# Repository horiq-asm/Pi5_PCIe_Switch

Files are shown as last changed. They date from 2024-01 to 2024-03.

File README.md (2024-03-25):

Pi5のPCIeコネクタ情報が公開されたのでASM1184eをつないでPCIe　M.2コネクタ4portの動作検証しました。<br>
結論としては4ポート認識とA-keyの2.5GbpsLAN基板,M-keyの各種USB3基板が動作しました。<br>
ただし、M.2SSDがまだ現状認識できていません。　　＜＜対策済　<br>
pcie信号間クロストーク対策と、電源強化を行ってM.2SSDは正常に認識されました。<br>
回路図はまだ公開しませんが実験基板のpcdデータをKicadで公開します。<br>
<br>
youtubeに動作画面を載せています。<br>
https://youtu.be/G8ONZqBu1oo

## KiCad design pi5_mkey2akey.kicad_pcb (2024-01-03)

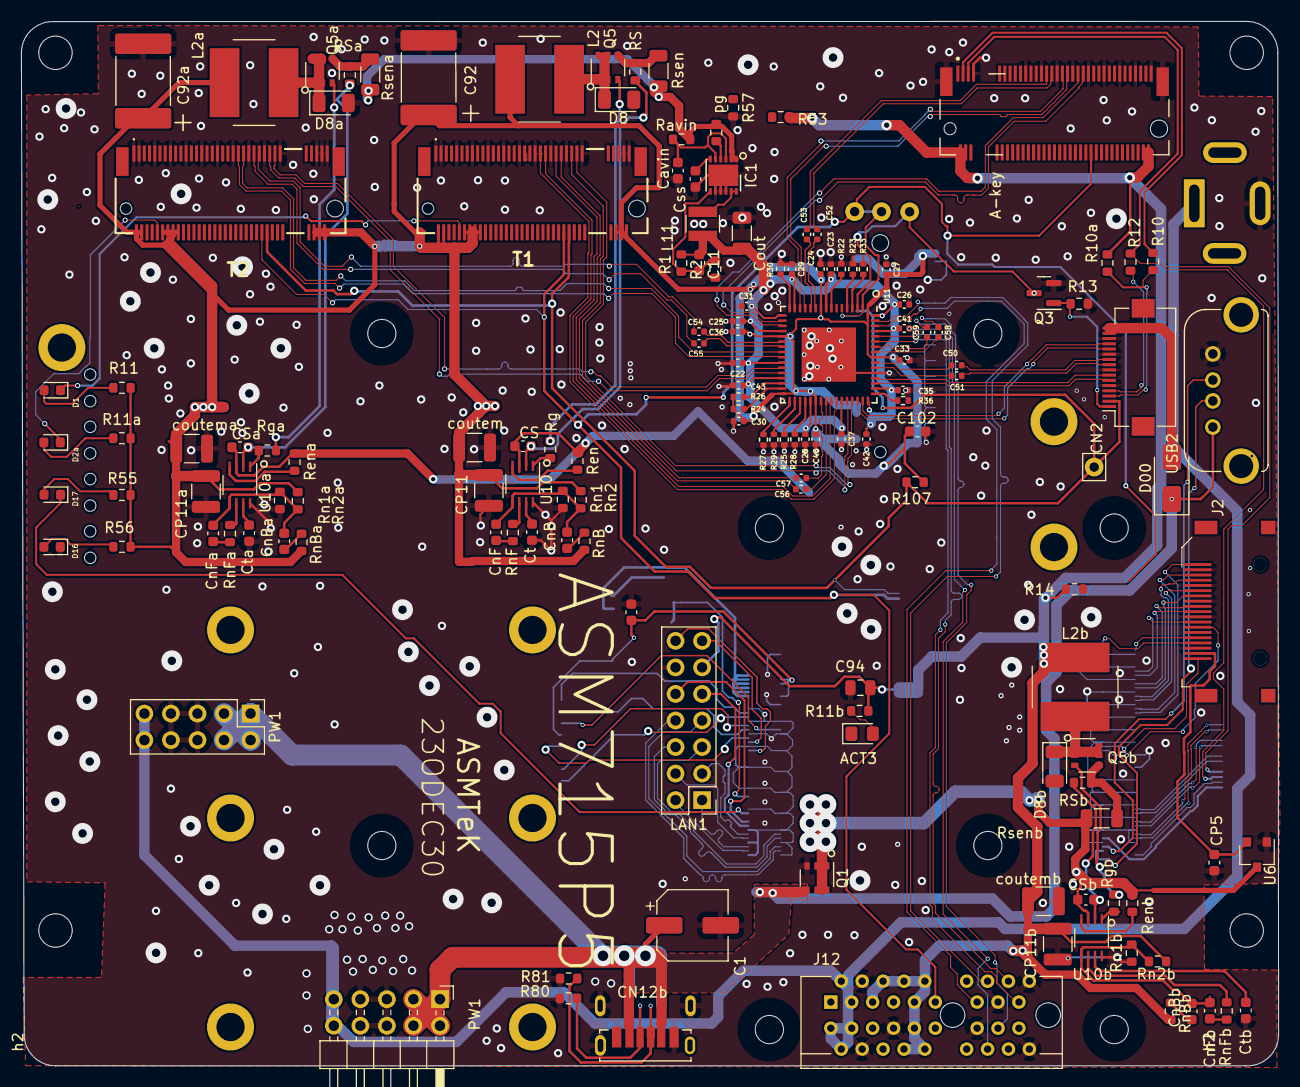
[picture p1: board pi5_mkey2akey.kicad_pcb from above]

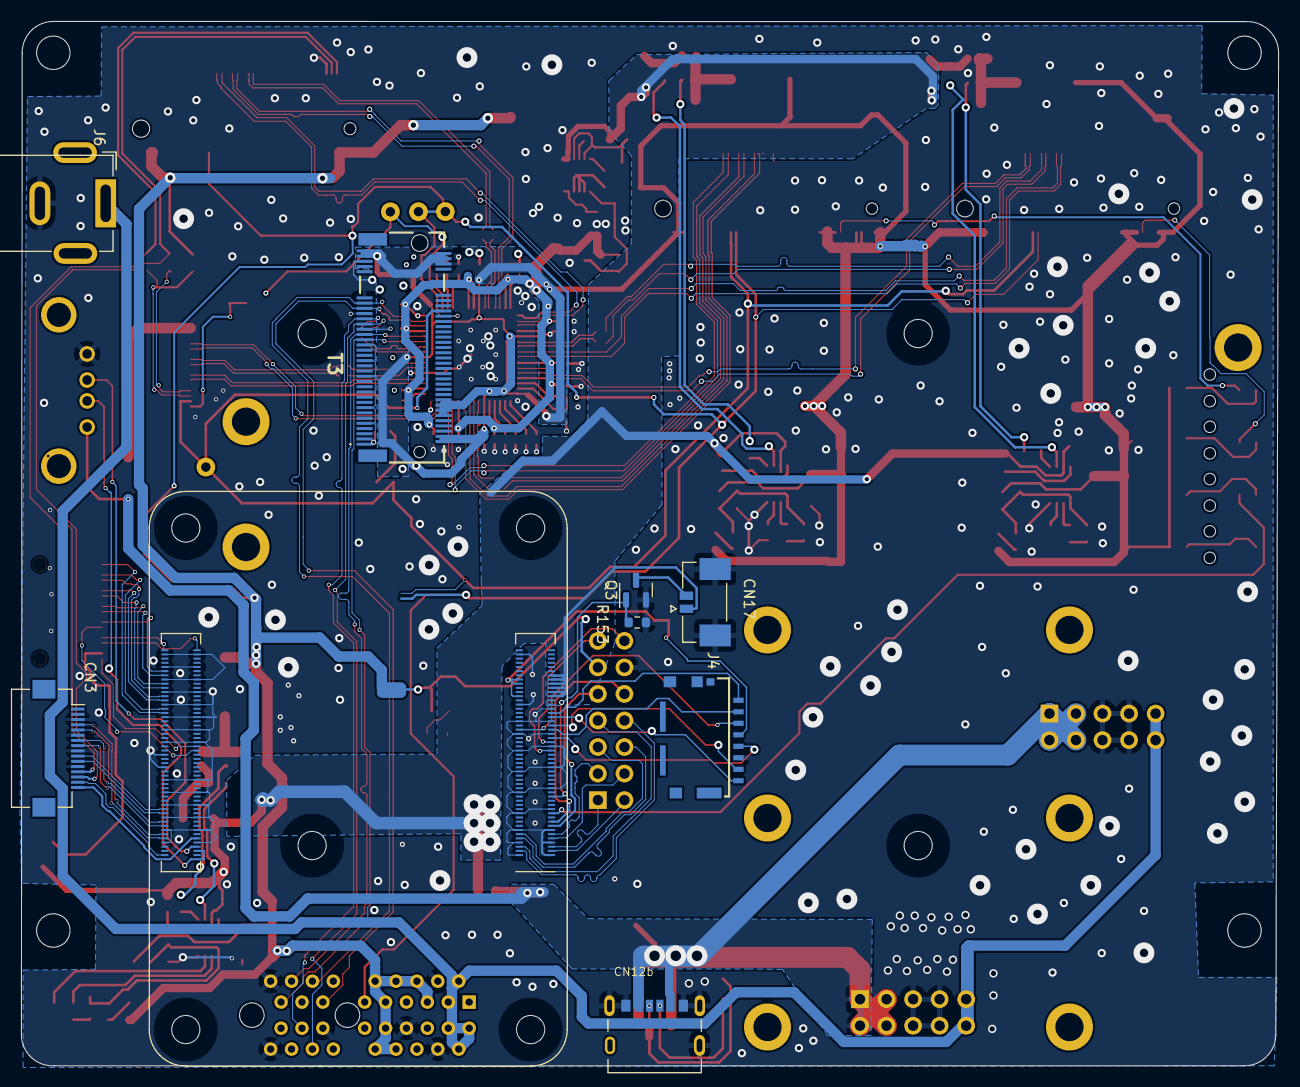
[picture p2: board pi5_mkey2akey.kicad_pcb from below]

Board: 2 copper layers, 120.3 x 100.0 mm, 167 parts (9 on the bottom side), 156 nets.

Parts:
C1: RSA0J331MCN1GS; CP_Elec_6.3x5.8
C11: 25p; C_0603_1608Metric
C22, C23, C24, C25, C26, C27, C28, C29, C30, C31, C33, C35, C36, C37, C41, C42, C43, C46, C50, C51, C52, C53, C54, C55, C56, C57, C58, C59: 100nF; C_0402_1005Metric
C92, C92a: ECASD40J476M025K00; C_2220_5650Metric_Pad1.97x5.40mm_HandSolder
C94: GRM188R61C106MAALD; C_0805_2012Metric
C102: 104; C_0603_1608Metric
CN2, CN3: Hirose_FH12-16S-0.5SH_1x16-1MP_P0.50mm_Horizontal
CN12b: CUI_UJC-VP-3-SMT-TR
CN12b#2: CUI_UJC-HP-3-SMT-TR
CN17: MOLEX_533980271
CP4: 100n; C_0603_1608Metric
CP5: 104; C_0603_1608Metric
CP11, CP11a, CP11b: C_1210_3225Metric
CS: 22n; C_0603_1608Metric
CSa: 22n; C_0603_1608Metric
CSb: 22n; C_0603_1608Metric
Cavin: 10n; C_0603_1608Metric
CnB: 220p; C_0603_1608Metric
CnBa: 220p; C_0603_1608Metric
CnBb: 220p; C_0603_1608Metric
CnF: 2.2n; C_0603_1608Metric
CnFa: 2.2n; C_0603_1608Metric
CnFb: 2.2n; C_0603_1608Metric
Cout: 22u; C_1206_3216Metric
Css: 470p; C_0603_1608Metric
Ct: 1n; C_0603_1608Metric
Cta: 1n; C_0603_1608Metric
Ctb: 1n; C_0603_1608Metric
D00: SR54F; D_SMA
D1, D2a: yellow; LED_0603_1608Metric
D1b: ACT3; LED_0805_2012Metric_Pad1.15x1.40mm_HandSolder
D8, D8a, D8b: SS2040FL; D_1206_3216Metric
D16: green; LED_0603_1608Metric
D17: red; LED_0603_1608Metric
IC1: RP510L00; DFN-12-1EP_3x3mm_P0.5mm_EP2.05x2.86mm
J2: HDMI_A_Female_2000-1-2-41-00-BK; HDMI
J4: 105162-0001
J6: BarrelJack_GCT_DCJ200-10-A_Horizontal
J12: 10018783-11200TLF; PCIex1-36
L2, L2a, L2b: SRN6045TA-4R7M; L_Bourns_SRN8040TA
L11: 1u; L_Abracon_ASPI-3012S
LAN1: PinHeader_2x07_P2.54mm_Vertical
Module1: ComputeModule4; Raspberry-Pi-4-Compute-Module
PW1: PinHeader_2x05_P2.54mm_Vertical
PW1#2: PinHeader_2x05_P2.54mm_Horizontal
Q1, Q5, Q5a, Q5b: SSM6J808R; TSOP-6_1.65x3.05mm_P0.95mm
Q3, Q3#2: BSS138-TP; SOT-23
R1, R2: 20k; R_0603_1608Metric
R10, R12: 0; R_0603_1608Metric
R10a: 2.2k; R_0603_1608Metric
R11, R11a, R11b, R55, R56, R153: 1k; R_0603_1608Metric
R13: 10k; R_0603_1608Metric
R14, R80, R81: 5.1k; R_0603_1608Metric
R22, R23, R25, R27: 1K; R_0402_1005Metric
R24, R26, R28, R29, R33: 10K; R_0402_1005Metric
R30, R36: 12.1K; R_0402_1005Metric
R53, R57: 51k; R_0603_1608Metric
R107: 100k; R_0603_1608Metric
RS: 20; R_0603_1608Metric
RSa: 20; R_0603_1608Metric
RSb: 20; R_0603_1608Metric
Ravin: 1; R_0603_1608Metric
Ren: 10k; R_0603_1608Metric
Rena: 10k; R_0603_1608Metric
Renb: 10k; R_0603_1608Metric
Rg: 20; R_0603_1608Metric
Rga: 20; R_0603_1608Metric
Rgb: 20; R_0603_1608Metric
Rn1, Rn1a, Rn1b: 10k; R_0603_1608Metric
Rn2, Rn2a, Rn2b: 30.9k; R_0603_1608Metric
RnB: 1k; R_0603_1608Metric
RnBa: 1k; R_0603_1608Metric
RnBb: 1k; R_0603_1608Metric
RnF: 8.2k; R_0603_1608Metric
RnFa: 8.2k; R_0603_1608Metric
RnFb: 8.2k; R_0603_1608Metric
Rsen: 27m; R_1206_3216Metric
Rsena: 27m; R_1206_3216Metric
Rsenb: 27m; R_1206_3216Metric
T1, T2, T3: MDT420M01001
T4: 2199230-8; b9973afb-34f9-4941-8c1f-dffebdb6dde0
U6: AP2331W; SC-59
U10, U10a, U10b: NJW4160R-TE2; SOT-23-8_Handsoldering
U11: ASM1184e; QFN-64-1EP_9x9mm_P0.5mm_EP5.2x5.2mm
USB2: USB-A-S-X-X-VT
coutem: C_1210_3225Metric
coutema: C_1210_3225Metric
coutemb: C_1210_3225Metric
h2, h2#2, h10, h15: MountingHole_3.2mm_M3
h4, h4#2, h6, h7: SLP3-150-100-F; MountingHole_2.1mm
h5, h5#2, h5#3, h5#4: MountingHole_1.1mm; MountingHole_2.1mm
pg: 100k; R_0603_1608Metric

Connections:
1v2: C11.2, C22.1, C23.1, C25.1, C26.1, C28.1, C29.1, C31.1, C35.1, C37.1, C41.1, C42.1, C43.1, Cout.1, L11.2, R1.2, U11.9 (1V2), U11.15 (1V2), U11.17 (1V2), U11.20 (1V2), U11.26 (1V2), U11.29 (1V2), U11.37 (1V2), U11.43 (1V2), U11.48 (1V2), U11.50 (1V2), U11.61 (1V2), U11.64 (1V2)
3.3V: C94.2, CP11b.2, J12.A5 (TCK), J12.A6 (TDI), J12.A8 (TMS), J12.A9 (+3.3V), J12.A10 (+3.3V), J12.B8 (+3.3v), J12.B9 (nTRST), J12.B10 (+3.3vAUX), L2b.2, LAN1.11, R10a.1, R11b.2, R14.1, R53.1, Rn2b.1, RnBb.1, T4.2, T4.4, T4.72, T4.74, coutemb.1
3.3vema: C24.1, C27.1, C30.1, C33.1, C36.1, C46.1, C92.1, C92a.1, C102.1, CP11.2, CP11a.2, L2.2, L2a.2, R11.2, R11a.2, R24.1, R26.1, R55.2, R56.2, R107.2, Rn2.1, Rn2a.1, RnB.1, RnBa.1, T1.2, T1.4, T1.12, T1.14, T1.16, T1.18, T1.70, T1.72, T1.74, T2.2, T2.4, T2.12, T2.14, T2.16, T2.18, T2.70, T2.72, T2.74, T3.2, T3.4, T3.12, T3.14, T3.16, T3.18, T3.70, T3.72, T3.73, T3.74, T3.75, U11.1 (3V_AUX), U11.10 (3V3), U11.21 (3V3), U11.32 (3V3), U11.38 (3V3), U11.56 (3V3), coutem.1, coutema.1
5VIN: C1.1, CN12b.A9, CN12b.B9, CN12b#2.A9, CN12b#2.B9, D00.1, PW1.1, PW1.2, PW1.3, PW1.4, PW1#2.1, PW1#2.2, PW1#2.3, PW1#2.4, Q1.4, USB2.1
12V: J6.1, J12.A2 (+12V), J12.A3 (+12V), J12.B1 (+12v), J12.B2 (+12v), J12.B3 (+12v), PW1.9, PW1.10, PW1#2.9, PW1#2.10
1184e_TX_N: C51.2, U11.54 (TXP_IN)
1184e_TX_P: C50.2, U11.55 (TXN_IN)
A5: CN12b.A5, CN12b#2.B5, R81.1
B5: CN12b.B5, CN12b#2.A5, R80.1
Ethernet_Pair0_N: LAN1.6, Module1.10 (Ethernet_Pair0_N)
Ethernet_Pair0_P: LAN1.5, Module1.12 (Ethernet_Pair0_P)
Ethernet_Pair1_N: LAN1.7, Module1.6 (Ethernet_Pair1_N)
Ethernet_Pair1_P: LAN1.8, Module1.4 (Ethernet_Pair1_P)
Ethernet_Pair2_N: LAN1.4, Module1.9 (Ethernet_Pair2_N)
Ethernet_Pair2_P: LAN1.3, Module1.11 (Ethernet_Pair2_P)
Ethernet_Pair3_N: LAN1.1, Module1.5 (Ethernet_Pair3_N)
Ethernet_Pair3_P: LAN1.2, Module1.3 (Ethernet_Pair3_P)
Ethernet_nLED2: LAN1.10, Module1.17 (Ethernet_nLED2(3.3v))
Ethernet_nLED3: LAN1.9, Module1.15 (Ethernet_nLED3(3.3v))
GND: C1.2, C22.2, C23.2, C24.2, C25.2, C26.2, C27.2, C28.2, C29.2, C30.2, C31.2, C33.2, C35.2, C36.2, C37.2, C41.2, C42.2, C43.2, C46.2, C92.2, C92a.2, C94.1, C102.2, CN2.5, CN2.8, CN2.11, CN2.14, CN3.3, CN3.6, CN3.9, CN3.12, CN12b.A12, CN12b.B12, CN12b.S1, CN12b#2.A12, CN12b#2.B12, CN12b#2.S1, CN12b#2.S2, CN12b#2.S4, CN17.S1, CN17.S2, CP4.1, CP5.1, CP11.1, CP11a.1, CP11b.1, Cavin.1, Cout.2, Css.1, Ct.2, Cta.2, Ctb.2, D8.2, D8a.2, D8b.2, D16.1, IC1.8, IC1.9, IC1.10, IC1.13, J2.2, J2.5, J2.8, J2.11, J2.17, J4.6, J6.2, J12.A4 (GND), J12.A15 (GND), J12.A18 (GND), J12.B4 (GND), J12.B7 (GND), J12.B13 (GND), J12.B18 (GND), LAN1.12, Module1.1 (GND), Module1.2 (GND), Module1.7 (GND), Module1.8 (GND), Module1.13 (GND), Module1.14 (GND), Module1.22 (GND), Module1.23 (GND), Module1.32 (GND), Module1.33 (GND), Module1.42 (GND), Module1.43 (GND), Module1.52 (GND), Module1.53 (GND), Module1.59 (GND), Module1.60 (GND), Module1.65 (GND), Module1.66 (GND), Module1.71 (GND), Module1.74 (GND), Module1.98 (GND), Module1.107 (GND), Module1.108 (GND), Module1.113 (GND), Module1.114 (GND), Module1.119 (GND), Module1.120 (GND), Module1.125 (GND), Module1.126 (GND), Module1.131 (GND), Module1.132 (GND), Module1.137 (GND), Module1.138 (GND), Module1.144 (GND), Module1.150 (GND), Module1.155 (GND), Module1.156 (GND), Module1.161 (GND), Module1.162 (GND), Module1.167 (GND), Module1.168 (GND), Module1.173 (GND), Module1.174 (GND), Module1.179 (GND), Module1.180 (GND), Module1.185 (GND), Module1.186 (GND), Module1.191 (GND), Module1.192 (GND), Module1.197 (GND), Module1.198 (GND), PW1.5, PW1.6, PW1.7, PW1.8, PW1#2.5, PW1#2.6, PW1#2.7, PW1#2.8, Q1.3, Q3.2, Q3#2.2, R2.1, R13.2, R22.2, R23.2, R25.2, R27.2, R28.1, R29.1, R30.2, R33.1, R36.2, R57.1, R80.2, R81.2, R153.1, Rn1.2, Rn1a.2, Rn1b.2, T1.1, T1.3, T1.9, T1.15, T1.21, T1.27, T1.33, T1.39, T1.45, T1.51, T1.57, T1.71, T1.73, T1.75, T2.1, T2.3, T2.9, T2.15, T2.21, T2.27, T2.33, T2.39, T2.45, T2.51, T2.57, T2.71, T2.73, T2.75, T3.1, T3.3, T3.9, T3.15, T3.21, T3.27, T3.33, T3.39, T3.45, T3.51, T3.57, T3.71, T4.7, T4.27, T4.33, T4.39, T4.45, T4.51, T4.57, T4.63, T4.69, T4.75, T4.S1, T4.S2, U6.1, U10.8, U10a.8, U10b.8, U11.53 (GND), U11.65 (GND), USB2.4, coutem.2, coutema.2, coutemb.2
GPIO14: LAN1.13, Module1.55 (GPIO14)
GPIO15: LAN1.14, Module1.51 (GPIO15)
GPIO16: Module1.29 (GPIO16), Q3#2.1, R153.2
H5V: CP5.2, J2.18, U6.2
HDMI0_CEC: J2.13, Module1.151 (HDMI0_CEC)
HDMI0_CLK_N: J2.12, Module1.190 (HDMI0_CLK_N)
HDMI0_CLK_P: J2.10, Module1.188 (HDMI0_CLK_P)
HDMI0_SCL: J2.15, Module1.200 (HDMI0_SCL)
HDMI0_SDA: J2.16, Module1.199 (HDMI0_SDA)
HDMI0_TX0_N: J2.9, Module1.184 (HDMI0_TX0_N)
HDMI0_TX0_P: J2.7, Module1.182 (HDMI0_TX0_P)
HDMI0_TX1_N: J2.6, Module1.176 (HDMI0_TX1_P)
HDMI0_TX1_P: J2.4, Module1.178 (HDMI0_TX1_N)
HDMI0_TX2_N: J2.3, Module1.172 (HDMI0_TX2_N)
HDMI0_TX2_P: J2.1, Module1.170 (HDMI0_TX2_P)
HDMI_HOTPLUG: J2.19, Module1.153 (HDMI0_HOTPLUG)
HS3R+: CN2.3, R10.2, R10a.2
HS3R-: CN2.4, R12.2
HS3RN: CN3.14, R12.1, T4.5
HS3RP: CN3.13, R10.1, T4.3
MT1: CN17.2, Q3#2.3
NJ001: Rg.2, U10.1
NJ_g: Q5.3, Rg.1
Nj002: CS.2, RS.2, U10.2
Nj003: CnB.1, RnB.2
Nj005: CnB.2, CnF.2, Rn1.1, Rn2.2, U10.5
Nj007: Q5.4, RS.1, Rsen.2
Nj008: D8.1, L2.1, Q5.1, Q5.2, Q5.5, Q5.6
Nj009: RnF.1, U10.6
Nj010: CnF.1, RnF.2
Nj011: Ct.1, U10.7
Njen: Ren.2, U10.4
PCIE_CLK_2N: CN3.4, Module1.112 (PCIe_CLK_N)
PCIE_CLK_2P: CN3.5, Module1.110 (PCIe_CLK_P)
PCIE_CLK_nREQ2: CN3.15, Module1.102 (PCIe_CLK_nREQ)
PCIE_RX_2N: CN3.7, Module1.118 (PCIe_RX_N)
PCIE_RX_2P: CN3.8, Module1.116 (PCIe_RX_P)
PCIE_TX_2N: CN3.10, Module1.124 (PCIe_TX_N)
PCIE_TX_2P: CN3.11, Module1.122 (PCIe_TX_P)
PCIe_CLK_N: CN2.13, U11.47 (REFCLKN_IN)
PCIe_CLK_P: CN2.12, U11.46 (REFCLKP_IN)
PCIe_CLK_nREQ: CN2.2, R107.1, T1.52, T2.52, T3.52
PCIe_RX_N: C51.1, CN2.9
PCIe_RX_P: C50.1, CN2.10
PCIe_TX_N: CN2.6, U11.51 (RXP_IN)
PCIe_TX_P: CN2.7, U11.52 (RXN_IN)
PCIe_nRST: CN3.16, Module1.109 (PCIe_nRST)
Pi5_pRST: CN2.1, Q3.1, R13.1
Pi_nLED_Activity: D17.1, Module1.21 (PI_nLED_Activity)
RSTI: Q3.3, U11.3 (RES_IN)
RSTO: J12.A11 (nPERST), R14.2, T1.50, T2.50, T3.50, T4.52, U11.2 (RES_OUT)
SD_CLK: J4.5, Module1.57 (SD_CLK)
SD_CMD: J4.3, Module1.62 (SD_CMD)
SD_DATA0: J4.7, Module1.63 (SD_DAT0)
SD_DATA1: J4.8, Module1.67 (SD_DAT1)
SD_DATA2: J4.1, Module1.69 (SD_DAT2)
SD_DATA3: J4.2, Module1.61 (SD_DAT3)
SD_PWR: CP4.2, J4.4, Module1.78 (GPIO_VREF(1.8v/3.3v_Input)), Module1.84 (+3.3v_(Output)), Module1.86 (+3.3v_(Output))
USB_N: Module1.103 (USB2_N), USB2.2
USB_P: Module1.105 (USB2_P), USB2.3
VCC-2: CN17.1, CS.1, CSa.1, CSb.1, IC1.1, IC1.2, Module1.77 (+5v_(Input)), Module1.79 (+5v_(Input)), Module1.81 (+5v_(Input)), Module1.83 (+5v_(Input)), Module1.85 (+5v_(Input)), Module1.87 (+5v_(Input)), Q1.1, Q1.2, Q1.5, Q1.6, Ravin.2, Ren.1, Rena.1, Renb.1, Rsen.1, Rsena.1, Rsenb.1, U6.3, U10.3, U10a.3, U10b.3, pg.2
aNj001: Rga.2, U10a.1
aNj002: CSa.2, RSa.2, U10a.2
aNj003: CnBa.1, RnBa.2
aNj005: CnBa.2, CnFa.2, Rn1a.1, Rn2a.2, U10a.5
aNj007: Q5a.4, RSa.1, Rsena.2
aNj008: D8a.1, L2a.1, Q5a.1, Q5a.2, Q5a.5, Q5a.6
aNj009: RnFa.1, U10a.6
aNj010: CnFa.1, RnFa.2
aNj011: Cta.1, U10a.7
aNj_g: Q5a.3, Rga.1
aNjen: Rena.2, U10a.4
bNj001: Rgb.2, U10b.1
bNj002: CSb.2, RSb.2, U10b.2
bNj003: CnBb.1, RnBb.2
bNj005: CnBb.2, CnFb.2, Rn1b.1, Rn2b.2, U10b.5
bNj007: Q5b.4, RSb.1, Rsenb.2
bNj008: D8b.1, L2b.1, Q5b.1, Q5b.2, Q5b.5, Q5b.6
bNj009: RnFb.1, U10b.6
bNj010: CnFb.1, RnFb.2
bNj011: Ctb.1, U10b.7
bNj_g: Q5b.3, Rgb.1
bNjen: Renb.2, U10b.4
bm3das: D1b.1 (K), T3.10
exPWR: CN2.15, CN2.16, D00.2
exPWR2: CN3.1, CN3.2
fclk1+: T4.49, U11.18 (REFCLKP_1)
fclk1-: T4.47, U11.19 (REFCLKN_1)
fclk2+: T2.55, U11.27 (REFCLKP_2)
fclk2-: T2.53, U11.28 (REFCLKN_2)
fclk3+: T1.53, U11.44 (REFCLKP_3)
fclk3-: T1.55, U11.45 (REFCLKN_3)
fclk4+: J12.A13 (REFCLK+), T3.53, U11.62 (REFCLKP_4)
fclk4-: J12.A14 (REFCLK-), T3.55, U11.63 (REFCLKN_4)
h003: R33.2, U11.4 (GPIO_0)
h004: R23.1, U11.5 (GPIO_2)
h005: R22.1, U11.8 (GPIO_4)
h012: R30.1, U11.16 (REXT1)
h025: R26.2, U11.30 (GPIO_5)
h026: R24.2, U11.31 (GPIO_1)
h027: R27.1, U11.33 (TEST_EN)
h028: R29.2, U11.34 (GPIO_3)
h029: R25.1, U11.35 (GPIO_6)
h030: R28.2, U11.36 (GPIO_7)
m002: Cavin.2, IC1.3, IC1.5, Ravin.1
m003: IC1.4, pg.1
m3das: D1.1, T1.10
m3das2: D2a.1, T2.10
m004: Css.2, IC1.6
m005: C11.1, IC1.7, R1.1, R2.2
m006: IC1.11, IC1.12, L11.1
rext2: R36.1, U11.49 (REXT2)
rx1+: T4.43, U11.13 (RXP_1)
rx1-: T4.41, U11.14 (RXN_1)
rx2+: T2.43, U11.24 (RXP_2)
rx2-: T2.41, U11.25 (RXN_2)
rx3+: T1.43, U11.41 (RXP_3)
rx3-: T1.41, U11.42 (RXN_3)
rx4+: J12.A17 (PERN0), T3.41, U11.59 (RXP_4)
rx4-: J12.A16 (PERP0), T3.43, U11.60 (RXN_4)
tx1+: C52.2, U11.11 (TXP_1)
tx1-: C53.2, U11.12 (TXN_1)
tx1c+: C52.1, T4.37
tx1c-: C53.1, T4.35
tx2+: C54.2, U11.22 (TXP_2)
tx2-: C55.2, U11.23 (TXN_2)
tx2c+: C54.1, T2.49
tx2c-: C55.1, T2.47
tx3+: C57.2, U11.39 (TXP_3)
tx3-: C56.2, U11.40 (TXN_3)
tx3c+: C57.1, T1.49
tx3c-: C56.1, T1.47
tx4+: C58.2, U11.57 (TXP_4)
tx4-: C59.2, U11.58 (TXN_4)
tx4c+: C58.1, J12.B15 (PETN0), T3.49
tx4c-: C59.1, J12.B14 (PETP0), T3.47

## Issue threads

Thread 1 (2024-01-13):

Schematics and datasheet

phodina, 2024-01-13:
Hello,

could you also provide the schematics for the project?

Also do you have the asm118e4 datasheet?

Superfish1000, 2024-12-27:
https://drive.google.com/drive/folders/1-NK3TZmkWhnU8MXbgIJSZp1EgM8i-IpN

horiq-asm, 2024-12-27:
Thank you for the data sheet. I will look into the contents. I did not draw the circuit diagram in Kicad, so I will post it as a PDF.

horiq-asm, 2024-12-28:
https://github.com/horiq-asm/raspberrypi-CM4-M.2-Akey-Mkey-Bkey/blob/main/ASM741x3.pdf
ASM1184 peripheral circuit diagram uploaded
